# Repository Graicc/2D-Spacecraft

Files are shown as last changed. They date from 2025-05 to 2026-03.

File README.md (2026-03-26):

# Autonomous Hovercraft

Update video: Autonomous Hovercraft Overview 2026-03-26 (https://www.youtube.com/watch?v=7EvYRF6kqDI)

A work in progress project to demonstrate control of a 2D "spacecraft" using thrusters.

<!--![hovercraft](https://github.com/user-attachments/assets/41b691c9-8705-4386-bad5-4d76df7696c3)-->


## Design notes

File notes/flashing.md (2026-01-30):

To flash STM32 over USb:

```
2D-Spacecraft\flight-controller > cargo dfu --release
```

To flash ESP32 over USB:

```
2D-Spacecraft\rcs-controller > cargo run --release
```

## Setting up STM32 for flashing

No probe-rs because DFU

`cargo dfu` to build and flash.

Hold the boot button down when plugging in to enter DFU mode (required for flashing).

You need to use Zadig to swap usb drivers. Plug in the device into DFU mode, make sure the device is selected in the dropdown. May need to go into the menu to refresh available devices.

- cargo dfu needs libusb-win32
- betaflight needs WinUSB https://betaflight.com/docs/development/USB-Flashing

Configuration for the board I'm using:
https://github.com/betaflight/config/blob/master/configs/OMNIBUSF4SD/config.h

embassy_usb_logger

Probably want to use internal oscillator

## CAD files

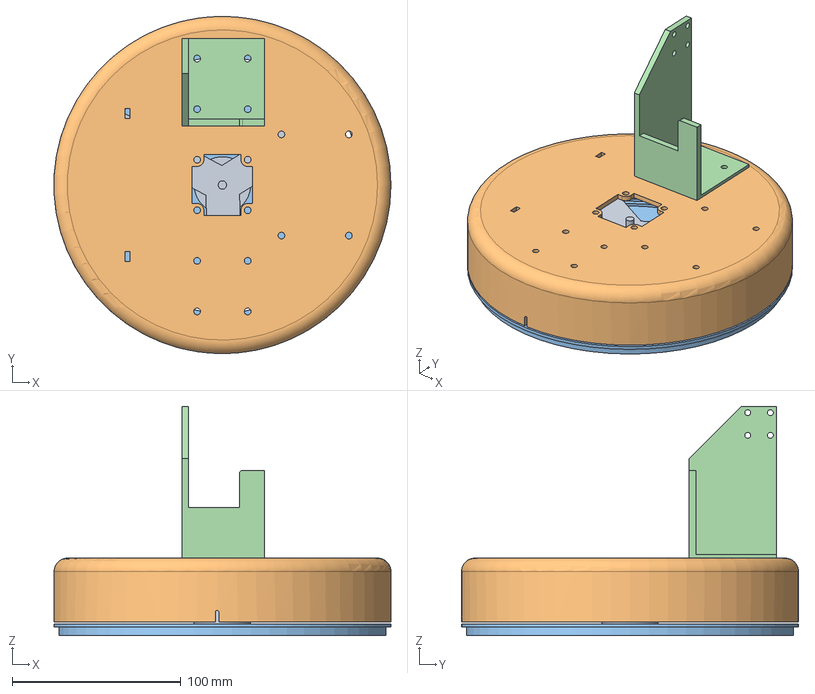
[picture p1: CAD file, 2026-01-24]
hardware/cad/SC2D.FCStd
199.9 x 199.9 x 136.0 mm
Motor
Base
MotorBracket

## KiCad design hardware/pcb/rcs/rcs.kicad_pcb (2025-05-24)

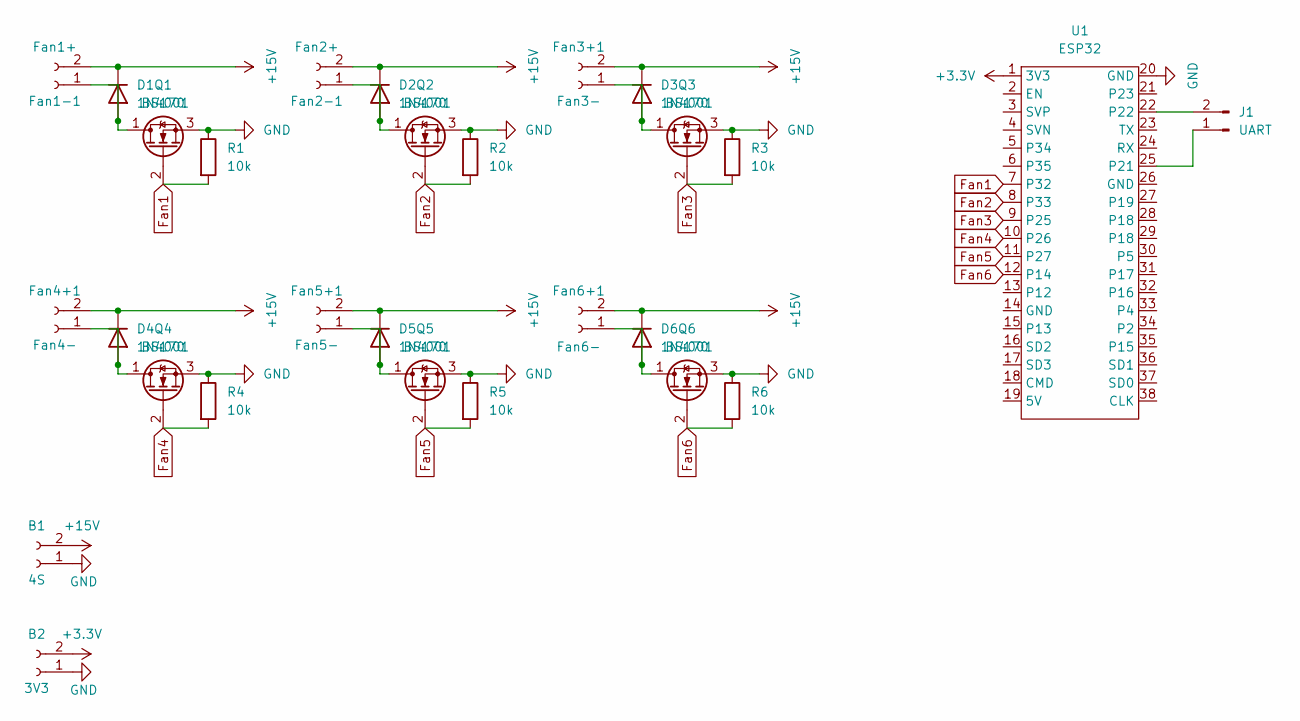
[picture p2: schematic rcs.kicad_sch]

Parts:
B1: 4S; PinHeader_1x02_P2.54mm_Vertical
B2: 3V3; PinHeader_1x02_P2.54mm_Vertical
D1, D2, D3, D4, D5, D6: 1N4001; D_DO-41_SOD81_P7.62mm_Horizontal
Fan1-1: Fan1+; PinHeader_1x02_P2.54mm_Vertical
Fan2-1: Fan2+; PinHeader_1x02_P2.54mm_Vertical
Fan3+1: Fan3-; PinHeader_1x02_P2.54mm_Vertical
Fan4+1: Fan4-; PinHeader_1x02_P2.54mm_Vertical
Fan5+1: Fan5-; PinHeader_1x02_P2.54mm_Vertical
Fan6+1: Fan6-; PinHeader_1x02_P2.54mm_Vertical
J1: UART; PinHeader_1x02_P2.54mm_Vertical
Q1, Q2, Q3, Q4, Q5, Q6: BS170; TO-92_Inline_Wide
R1, R2, R3, R4, R5, R6: 10k; R_Axial_DIN0614_L14.3mm_D5.7mm_P20.32mm_Horizontal
U1: ESP32

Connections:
+3.3V: B2.2, U1.1 (3V3)
+15V: B1.2, D1.1 (K), D2.1 (K), D3.1 (K), D4.1 (K), D5.1 (K), D6.1 (K), Fan1-1.2, Fan2-1.2, Fan3+1.2, Fan4+1.2, Fan5+1.2, Fan6+1.2
Fan1: Q1.2 (G), R1.2, U1.7 (P32)
Fan2: Q2.2 (G), R2.2, U1.8 (P33)
Fan3: Q3.2 (G), R3.2, U1.9 (P25)
Fan4: Q4.2 (G), R4.2, U1.10 (P26)
Fan5: Q5.2 (G), R5.2, U1.11 (P27)
Fan6: Q6.2 (G), R6.2, U1.12 (P14)
GND: B1.1, B2.1, Q1.3 (S), Q2.3 (S), Q3.3 (S), Q4.3 (S), Q5.3 (S), Q6.3 (S), R1.1, R2.1, R3.1, R4.1, R5.1, R6.1, U1.20 (GND)
unnamed: D1.2 (A), Fan1-1.1, Q1.1 (D)
unnamed: D2.2 (A), Fan2-1.1, Q2.1 (D)
unnamed: D3.2 (A), Fan3+1.1, Q3.1 (D)
unnamed: D4.2 (A), Fan4+1.1, Q4.1 (D)
unnamed: D5.2 (A), Fan5+1.1, Q5.1 (D)
unnamed: D6.2 (A), Fan6+1.1, Q6.1 (D)
unnamed: J1.1, U1.25 (P21)
unnamed: J1.2, U1.22

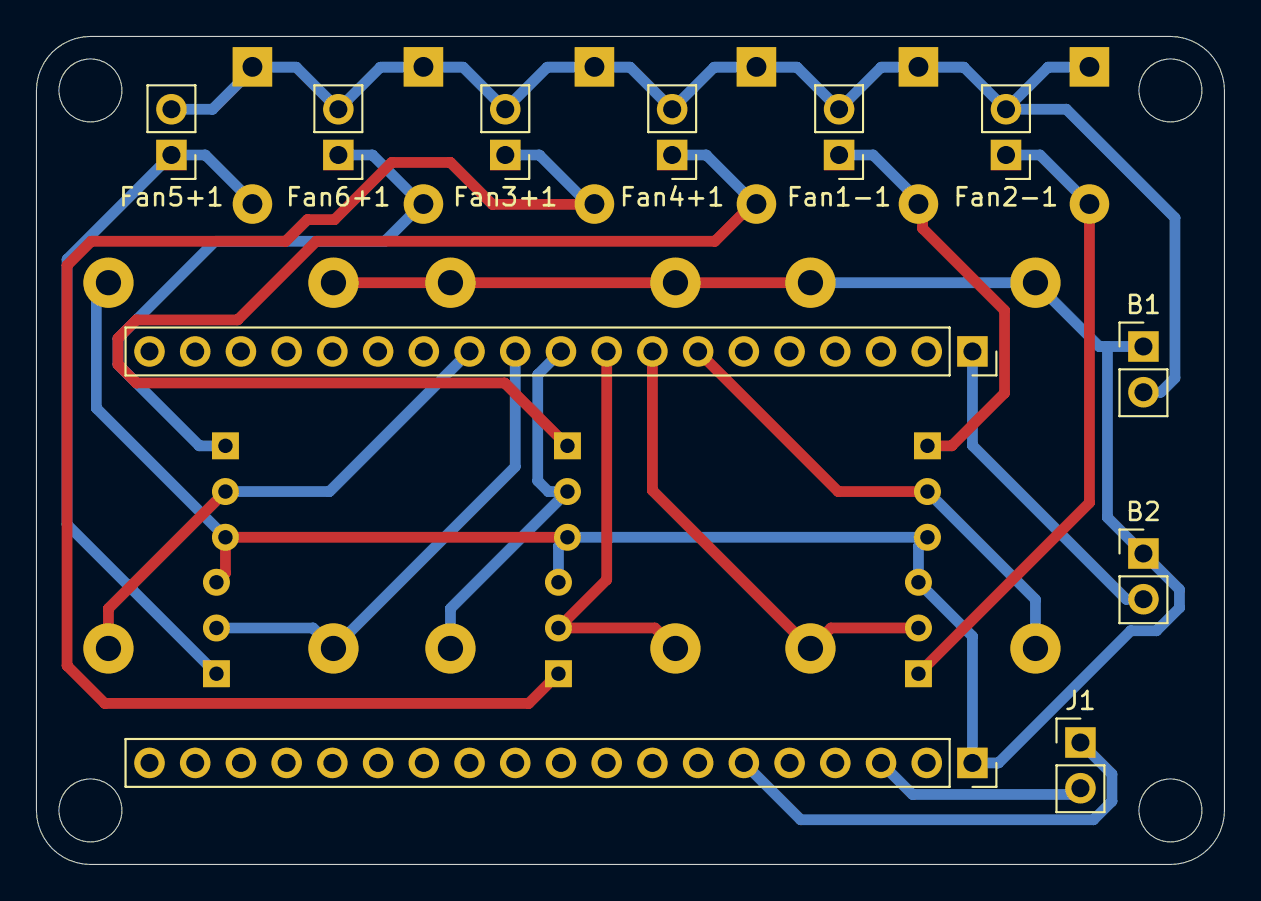
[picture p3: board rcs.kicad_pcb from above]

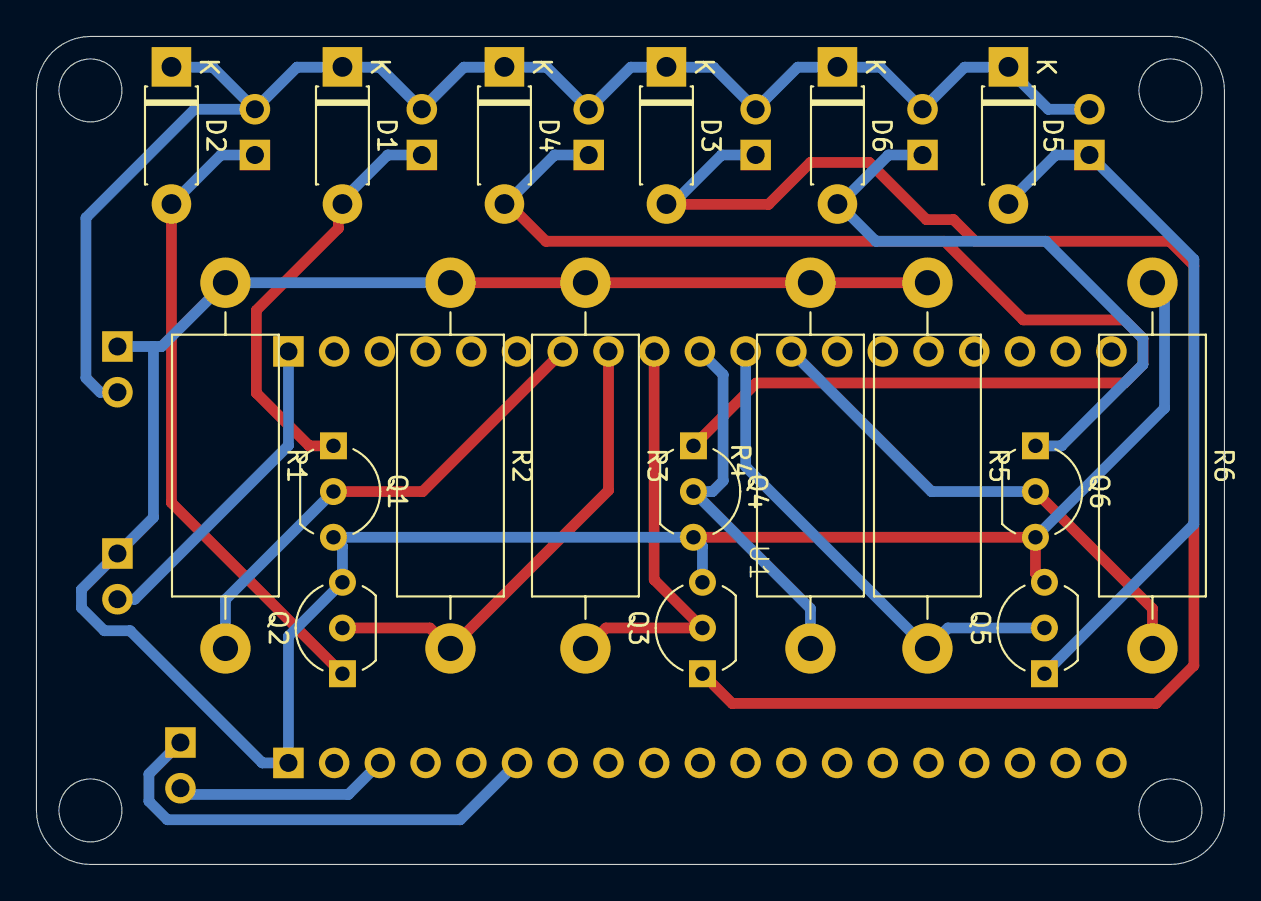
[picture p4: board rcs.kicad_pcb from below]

Board: 2 copper layers, 66.0 x 46.0 mm, 28 parts (18 on the bottom side), 17 nets.

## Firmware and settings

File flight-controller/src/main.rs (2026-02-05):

#![no_std]
#![no_main]

use assign_resources::assign_resources;
use embassy_executor::Spawner;
use embassy_futures::select::Either::{First, Second};
use embassy_futures::select::select;
use embassy_stm32::{Peri, usb};
use embassy_stm32::{
    gpio::{Level, Output, Speed},
    peripherals,
    time::Hertz,
};
use embassy_time::{Duration, Instant, Ticker};

use crate::battery_monitor::BATTERY_VOLTAGE;
use crate::imu::{CURRENT_IMU, CURRENT_STATE};
use crate::logger::logger_task;
use crate::motor::SET_MOTOR_STATE;
use crate::state::State;

use messages::{self, Message};

mod battery_monitor;
mod imu;
mod logger;
mod motor;
mod state;

assign_resources! {
    logger: LoggerResource {
        peri: USB_OTG_FS,
        dp: PA12,
        dm: PA11,
    },
    imu: IMUResource {
        peri: SPI1,
        sck: PA5,
        mosi: PA7,
        miso: PA6,
        cs: PA4
    },
    motor: MotorResource {
        // Motor 1: Left prop
        // Motor 2: Unused
        // Motor 3: Right prop
        // Motor 4: Base
        motor_1_pin: PB0,
        motor_2_pin: PB1,
        motor_3_pin: PA3,
        motor_4_pin: PA2,
        tim2: TIM2,
        tim3: TIM3,
    },
    battery_monitor: BatteryMonitorResource {
        adc: ADC1,
        pin: PC2,
        dma: DMA2_CH0
    }
}

embassy_stm32::bind_interrupts!(struct SerialPort1IRQs {
    USART1 => embassy_stm32::usart::InterruptHandler<embassy_stm32::peripherals::USART1>;
});

embassy_stm32::bind_interrupts!(struct Irqs {
    OTG_FS => usb::InterruptHandler<peripherals::USB_OTG_FS>;
});

#[embassy_executor::main]
async fn main(spawner: Spawner) -> ! {
    let config = {
        let mut config = embassy_stm32::Config::default();
        use embassy_stm32::rcc::*;
        config.rcc.hse = Some(Hse {
            freq: Hertz(8_000_000),
            // mode: HseMode::Bypass,
            mode: HseMode::Oscillator, // We want to use the internal oscillator! We don't have an external one
        });
        config.rcc.pll_src = PllSource::HSE;
        config.rcc.pll = Some(Pll {
            prediv: PllPreDiv::DIV4,
            mul: PllMul::MUL168,
            divp: Some(PllPDiv::DIV2), // 8mhz / 4 * 168 / 2 = 168Mhz.
            divq: Some(PllQDiv::DIV7), // 8mhz / 4 * 168 / 7 = 48Mhz.
            divr: None,
        });
        config.rcc.ahb_pre = AHBPrescaler::DIV1;
        config.rcc.apb1_pre = APBPrescaler::DIV4;
        config.rcc.apb2_pre = APBPrescaler::DIV2;
        config.rcc.sys = Sysclk::PLL1_P;
        config.rcc.mux.clk48sel = mux::Clk48sel::PLL1_Q;
        config
    };

    let p = embassy_stm32::init(config);
    let r = split_resources!(p);

    {
        const EP_OUT_BUFFER_SIZE: usize = 10 * 1024;
        pub static EP_OUT_BUFFER: static_cell::StaticCell<[u8; EP_OUT_BUFFER_SIZE]> =
            static_cell::StaticCell::new();
        let mut config = embassy_stm32::usb::Config::default();
        config.vbus_detection = false;
        let usb_driver = embassy_stm32::usb::Driver::new_fs(
            r.logger.peri,
            Irqs,
            r.logger.dp,
            r.logger.dm,
            EP_OUT_BUFFER.init([0; _]),
            config,
        );
        spawner.spawn(logger_task(usb_driver)).unwrap();
    }

    spawner.spawn(imu::imu_task(r.imu)).unwrap();

    spawner.spawn(motor::motor_task(r.motor)).unwrap();

    spawner
        .spawn(battery_monitor::battery_monitor_task(r.battery_monitor))
        .unwrap();

    // Onboard led
    let mut led: Output<'_> = Output::new(p.PB5, Level::High, Speed::Low);
    led.set_low();

    let mut uart_config = embassy_stm32::usart::Config::default();
    uart_config.baudrate = 115_200;
    let uart = embassy_stm32::usart::Uart::new(
        p.USART1,
        p.PA10,
        p.PA9,
        SerialPort1IRQs,
        p.DMA2_CH7,
        p.DMA2_CH2,
        uart_config,
    )
    .unwrap();
    let (mut uart_tx, uart_rx) = uart.split();
    let mut uart_rx_buf = [0u8; 1024];
    let mut uart_rx = uart_rx.into_ring_buffered(&mut uart_rx_buf);

    let mut receiver: messages::Receiver<Message, 256, 32> = messages::Receiver::new();

    let mut last_heartbeat = Instant::now();

    let mut last_voltage: u32 = 0;
    let mut current_motor_values: messages::MotorValues = Default::default();

    let mut ticker = Ticker::every(Duration::from_millis(10));
    loop {
        let state = CURRENT_STATE.wait().await;

        let target_state: State = Default::default();

        let err = target_state - state;

        // Just doing a P controller for now
        let cmd_vel = messages::CMDVelValues {
            vx: err.px * 0.1,
            vy: err.py * 0.1,
            vt: err.pt * 0.1,
        };
        let message = messages::Message::CMDVel(cmd_vel);

        match messages::send(&mut uart_tx, &message).await {
            Ok(_) => {}
            Err(_) => log::error!("Failed to send message"),
        }

        last_voltage = BATTERY_VOLTAGE.try_take().unwrap_or(last_voltage);

        if let Some(imu_status) = CURRENT_IMU.try_take() {
            match messages::send(
                &mut uart_tx,
                &messages::Message::StateUpdate(messages::StateUpdate {
                    imu_status,
                    voltage: last_voltage,
                    motor_values: current_motor_values.clone(),
                }),
            )
            .await
            {
                Ok(_) => {}
                Err(_) => log::error!("Failed to send IMU"),
            }
        }

        match select(receiver.receive(&mut uart_rx), ticker.next()).await {
            First(Ok(Message::HeartBeat)) => last_heartbeat = Instant::now(),
            First(Ok(Message::MotorValues(motor_values))) => {
                log::info!("Motor values: {:?}", &motor_values);
                current_motor_values = motor_values;
                SET_MOTOR_STATE.signal(current_motor_values.clone());
            }
            First(Ok(Message::CMDVel(_) | Message::StateUpdate(_))) => todo!(),
            First(Err(_)) => todo!(),
            Second(_) => {}
        }

        if (Instant::now() - last_heartbeat).as_secs() > 2 {
            log::error!("Heartbeat time out!");
            current_motor_values = Default::default();
            SET_MOTOR_STATE.signal(Default::default());
            led.set_high(); // Show error
        }
    }
}

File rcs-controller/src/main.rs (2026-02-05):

#![no_std]
#![no_main]
#![deny(
    clippy::mem_forget,
    reason = "mem::forget is generally not safe to do with esp_hal types, especially those \
    holding buffers for the duration of a data transfer."
)]

use crate::{
    control::control_task,
    messaging::{messaging_task, CURRENT_STATE, MESSAGES_TO_SEND},
    wifi::UdpConnection,
};
use defmt::{debug, println};
use embassy_executor::Spawner;
use embassy_futures::select::{select, Either};
use embassy_net::{udp::UdpSocket, DhcpConfig, StackResources};
use embassy_time::{Duration, Timer};
use esp_hal::{assign_resources, clock::CpuClock};
use esp_radio::wifi::{ClientConfig, ModeConfig};
use messages::{Message, WifiMessage};
use {esp_backtrace as _, esp_println as _};

mod control;
mod messaging;
mod wifi;

assign_resources! {
    Resources<'d> {
        wifi: WifiResources<'d> {
            wifi: WIFI,
        }
    }
}

// From https://github.com/esp-rs/esp-hal/blob/main/examples/wifi/embassy_access_point_with_sta/src/main.rs
macro_rules! mk_static {
    ($t:ty,$val:expr) => {{
        static STATIC_CELL: static_cell::StaticCell<$t> = static_cell::StaticCell::new();
        #[deny(unused_attributes)]
        let x = STATIC_CELL.uninit().write($val);
        x
    }};
}

// This creates a default app-descriptor required by the esp-idf bootloader.
// For more information see: <https://docs.espressif.com/projects/esp-idf/en/stable/esp32/api-reference/system/app_image_format.html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>
esp_bootloader_esp_idf::esp_app_desc!();

#[esp_rtos::main]
async fn main(spawner: Spawner) {
    let config = esp_hal::Config::default().with_cpu_clock(CpuClock::max());
    let p = esp_hal::init(config);

    let timg0 = esp_hal::timer::timg::TimerGroup::new(p.TIMG0);
    esp_rtos::start(timg0.timer0);

    let r = split_resources!(p);

    esp_alloc::heap_allocator!(#[esp_hal::ram(reclaimed)] size: 64 * 1024);
    esp_alloc::heap_allocator!(size: 36 * 1024);

    spawner
        .spawn(messaging_task(p.UART0, p.GPIO21, p.GPIO22))
        .unwrap();

    spawner
        .spawn(control_task(
            p.LEDC, p.GPIO14, p.GPIO27, p.GPIO26, p.GPIO25, p.GPIO33, p.GPIO32,
        ))
        .unwrap();

    {
        let esp_radio_ctrl = mk_static!(esp_radio::Controller, esp_radio::init().unwrap());

        let (mut controller, interfaces) =
            esp_radio::wifi::new(esp_radio_ctrl, r.wifi.wifi, Default::default()).unwrap();

        const SSID: &str = "craig";
        const PASSWORD: &str = "tacholycos";

        let wifi_sta_device = interfaces.sta;
        let mut dhcp_config: DhcpConfig = Default::default();
        let hostname: heapless::String<32> = heapless::String::try_from("ESP32").unwrap();
        dhcp_config.hostname = Some(hostname);
        let sta_config = embassy_net::Config::dhcpv4(dhcp_config);

        let rng = esp_hal::rng::Rng::new();
        let seed = (rng.random() as u64) << 32 | rng.random() as u64;

        let (sta_stack, sta_runner) = embassy_net::new(
            wifi_sta_device,
            sta_config,
            mk_static!(StackResources<4>, StackResources::<4>::new()),
            seed,
        );

        let station_config = ModeConfig::Client(
            ClientConfig::default()
                .with_ssid(SSID.into())
                .with_password(PASSWORD.into()),
        );
        controller.set_config(&station_config).unwrap();

        spawner.spawn(wifi::connection(controller)).unwrap();
        spawner.spawn(wifi::net_task(sta_runner)).unwrap();

        let sta_address = loop {
            if let Some(config) = sta_stack.config_v4() {
                let address = config.address.address();
                println!("Got IP: {}", address.octets());
                break address;
            }
            println!("Waiting for IP...");
            Timer::after(Duration::from_millis(500)).await;
        };

        println!(
            "connect to the ap `{}` and point your browser to http://{}:8080/",
            SSID,
            sta_address.octets()
        );

        let mut rx_buffer: [u8; _] = [0; 4096];
        let mut tx_buffer: [u8; _] = [0; 4096];
        let mut rx_meta = [embassy_net::udp::PacketMetadata::EMPTY; 16];
        let mut tx_meta = [embassy_net::udp::PacketMetadata::EMPTY; 16];
        let mut socket = UdpSocket::new(
            sta_stack,
            &mut rx_meta,
            &mut rx_buffer,
            &mut tx_meta,
            &mut tx_buffer,
        );
        socket.bind((sta_address, 1234)).unwrap();

        let mut udp_connection = UdpConnection::new(socket);

        println!("Waiting for first packet to identify host");
        let _data = messages::receive_single_read::<WifiMessage, _>(&mut udp_connection)
            .await
            .unwrap();
        println!("Got first packet");

        loop {
            match select(
                messages::receive_single_read::<WifiMessage, _>(&mut udp_connection),
                CURRENT_STATE.wait(),
            )
            .await
            {
                Either::First(Ok(WifiMessage::Ping(num))) => {
                    debug!("Got ping, sending pong");
                    messages::send(&mut udp_connection, &WifiMessage::Pong(num))
                        .await
                        .unwrap();
                }
                Either::First(Ok(WifiMessage::MotorValues(motor_values))) => {
                    MESSAGES_TO_SEND
                        .send(Message::MotorValues(motor_values))
                        .await;
                }
                Either::First(Ok(WifiMessage::HeartBeat)) => {
                    MESSAGES_TO_SEND.send(Message::HeartBeat).await;
                }
                Either::First(Ok(WifiMessage::Pong(_) | WifiMessage::StateUpdate(_))) => {
                    todo!()
                }
                Either::First(Err(_)) => {}
                Either::Second(state_update) => {
                    debug!("Sending IMU reading");
                    messages::send(&mut udp_connection, &WifiMessage::StateUpdate(state_update))
                        .await
                        .unwrap();
                }
            }
        }
    }
}

mod tests {}

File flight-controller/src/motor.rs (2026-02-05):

use embassy_stm32::{time::hz, timer::simple_pwm::SimplePwmChannels};
use embassy_sync::{blocking_mutex::raw::CriticalSectionRawMutex, signal::Signal};

const PWM_DENOM: u32 = 2083;
const PWM_ZERO: u32 = 1000;
const PWM_BASE_ON: u32 = 2000;
const PWM_FAN_ON: u32 = 1337;

pub static SET_MOTOR_STATE: Signal<CriticalSectionRawMutex, messages::MotorValues> = Signal::new();

fn u8_to_fan_pwm(val: u8) -> u32 {
    PWM_ZERO + (val as u32 * (PWM_FAN_ON - PWM_ZERO) / (u8::MAX as u32))
}

fn u8_to_base_pwm(val: u8) -> u32 {
    PWM_ZERO + (val as u32 * (PWM_BASE_ON - PWM_ZERO) / (u8::MAX as u32))
}

#[embassy_executor::task]
pub async fn motor_task(motor: crate::MotorResource) {
    let motor_1_pin = embassy_stm32::timer::simple_pwm::PwmPin::new(
        motor.motor_1_pin,
        embassy_stm32::gpio::OutputType::PushPull,
    );
    let motor_2_pin = embassy_stm32::timer::simple_pwm::PwmPin::new(
        motor.motor_2_pin,
        embassy_stm32::gpio::OutputType::PushPull,
    );
    let motor_3_pin = embassy_stm32::timer::simple_pwm::PwmPin::new(
        motor.motor_3_pin,
        embassy_stm32::gpio::OutputType::PushPull,
    );
    let motor_4_pin = embassy_stm32::timer::simple_pwm::PwmPin::new(
        motor.motor_4_pin,
        embassy_stm32::gpio::OutputType::PushPull,
    );
    let mut pwm_a = embassy_stm32::timer::simple_pwm::SimplePwm::new(
        motor.tim3,
        None,
        None,
        Some(motor_1_pin),
        Some(motor_2_pin),
        // hz(16_000),
        hz(480),
        embassy_stm32::timer::low_level::CountingMode::EdgeAlignedUp,
    );
    let pwm_b = embassy_stm32::timer::simple_pwm::SimplePwm::new(
        motor.tim2,
        None,
        None,
        Some(motor_4_pin),
        Some(motor_3_pin),
        // hz(16_000),
        hz(480),
        embassy_stm32::timer::low_level::CountingMode::EdgeAlignedUp,
    );
    let mut left_motor = pwm_a.ch3();
    let SimplePwmChannels {
        ch1: _,
        ch2: _,
        ch3: mut base_motor,
        ch4: mut right_motor,
    } = pwm_b.split();

    left_motor.enable();
    right_motor.enable();
    base_motor.enable();

    left_motor.set_duty_cycle_fraction(PWM_ZERO, PWM_DENOM);
    right_motor.set_duty_cycle_fraction(PWM_ZERO, PWM_DENOM);
    base_motor.set_duty_cycle_fraction(PWM_ZERO, PWM_DENOM);

    loop {
        let motor_values = SET_MOTOR_STATE.wait().await;

        left_motor.set_duty_cycle_fraction(u8_to_fan_pwm(motor_values.left), PWM_DENOM);
        right_motor.set_duty_cycle_fraction(u8_to_fan_pwm(motor_values.right), PWM_DENOM);
        base_motor.set_duty_cycle_fraction(u8_to_base_pwm(motor_values.base), PWM_DENOM);
    }
}

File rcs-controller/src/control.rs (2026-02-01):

use defmt::println;
use embassy_time::{Duration, Ticker};
use esp_hal::gpio;
use esp_hal::ledc::channel::ChannelIFace;
use esp_hal::ledc::timer::TimerIFace;
use esp_hal::ledc::Ledc;
use esp_hal::ledc::{channel, timer, LSGlobalClkSource, LowSpeed};
use esp_hal::peripherals::{GPIO14, GPIO25, GPIO26, GPIO27, GPIO32, GPIO33, LEDC};
use esp_hal::time::Rate;
use {esp_backtrace as _, esp_println as _};

use crate::messaging;

fn cmd_vel_to_fans(cmd_vel: messages::CMDVelValues) -> nalgebra::Vector6<f32> {
    #[rustfmt::skip]
    let local_xyt_to_rcs = nalgebra::Matrix6x3::from_row_slice(&[
        0.0, -0.5, 1.0,
        0.0, -0.5, -1.0,
        -1.0, 0.0, 0.0,
        0.0, 0.5, 1.0,
        0.0, 0.5, -1.0,
        1.0, 0.0, 0.0,
    ]);

    local_xyt_to_rcs * nalgebra::Vector3::new(cmd_vel.vx, cmd_vel.vy, cmd_vel.vt)
}

#[embassy_executor::task]
pub async fn control_task(
    ledc: LEDC<'static>,
    p1: GPIO14<'static>,
    p2: GPIO27<'static>,
    p3: GPIO26<'static>,
    p4: GPIO25<'static>,
    p5: GPIO33<'static>,
    p6: GPIO32<'static>,
) {
    let mut ledc = Ledc::new(ledc);
    ledc.set_global_slow_clock(LSGlobalClkSource::APBClk);

    let mut lstimer0 = ledc.timer::<LowSpeed>(timer::Number::Timer0);
    lstimer0
        .configure(timer::config::Config {
            duty: timer::config::Duty::Duty5Bit,
            clock_source: timer::LSClockSource::APBClk,
            frequency: Rate::from_khz(24),
        })
        .unwrap();

    let mut fans = [
        ledc.channel(channel::Number::Channel0, p1),
        ledc.channel(channel::Number::Channel0, p2),
        ledc.channel(channel::Number::Channel0, p3),
        ledc.channel(channel::Number::Channel0, p4),
        ledc.channel(channel::Number::Channel0, p5),
        ledc.channel(channel::Number::Channel0, p6),
    ];
    for fan in &mut fans {
        fan.configure(channel::config::Config {
            timer: &lstimer0,
            duty_pct: 0,
            drive_mode: gpio::DriveMode::PushPull,
        })
        .unwrap();
    }

    for fan in &mut fans {
        fan.set_duty(0).unwrap();
    }

    let mut ticker = Ticker::every(Duration::from_millis(10));
    loop {
        let cmd_vel = messaging::CURRENT_CMD_VEL.wait().await;

        // println!("Setting fans!");
        let fan_speeds = cmd_vel_to_fans(cmd_vel);
        let fan_values = fan_speeds
            .iter()
            .map(|value| f32::clamp(value * 100.0 / 10.0, 0.0, 100.0) as u8);

        for (fan, value) in fans.iter_mut().zip(fan_values) {
            match fan.set_duty(value) {
                Ok(_) => (),
                Err(e) => println!("Error setting fan value to {}: {}", value, e),
            }
        }

        ticker.next().await;
    }
}

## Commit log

2025-02-02 Add initial CAD
    [SC2D.FCStd]
2025-02-20 Update hole sizing and add propeller
    [SC2D.FCStd]
2025-02-24 Add slot for motor wire, add mounting holes for flight controller
    [SC2D.FCStd]
2025-02-24 Add initial PCB
    [rcs.kicad_pcb, rcs.kicad_sch]
2025-02-26 Add ESP32 dev board schematic and footprint, make draft PCB
    [rcs.kicad_pcb, rcs.kicad_sch]
2025-03-01 More compact PCB layout
    [rcs.kicad_pcb, rcs.kicad_sch]
2025-03-05 Add minimum trace width and screw holes
    [SC2D.FCStd, rcs.kicad_pcb, rcs.kicad_sch]
2025-03-07 Increase trace width to 0.3mm
    [rcs.kicad_pcb, rcs.kicad_sch]
2025-03-09 Increase trace width to 0.6mm
    [rcs.kicad_pcb]
2025-04-14 Fix ESP32 USB port location
    [rcs.kicad_pcb, rcs.kicad_sch]
2025-04-14 Add fan mount, use assembly
    [SC2D.FCStd]
2025-04-22 Send PWM signal to hover
2025-04-22 Add rcs-controller fan testing
2025-05-07 Update fan mount for height and lock nuts
    [SC2D.FCStd]
2025-05-23 Add flyback diodes
    [rcs.kicad_pcb, rcs.kicad_sch]
2025-05-24 Fix flyback diode orientation, round pcb corners
    [rcs.kicad_pcb, rcs.kicad_sch]
2025-09-06 Read accelerometer values
2025-09-07 Expirement with state estimation from IMU data
    [MPU6000_stationary_down.csv, MPU6000_stationary_up.csv]
2025-09-07 Record IMU data
    [MPU6000_stationary_down.csv, MPU6000_stationary_up.csv]
2025-10-11 Switch off of workspaces
2025-10-11 flight-controller enable motor
2026-01-02 Add camera calibration
2026-01-02 Add calibration script
2026-01-24 Add motor brackets for 2 motor design
    [SC2D.FCStd]
2026-01-30 Switch back to workspace
2026-01-31 Get ESP32 wifi ping-pong working
2026-01-31 Set ESP32 hostname
2026-02-01 Send IMU data to gui
2026-02-05 Add motor control from GUI, add voltage monitor
